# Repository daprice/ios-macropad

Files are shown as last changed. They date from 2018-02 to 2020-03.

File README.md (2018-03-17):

# Airpad
A tiny (3x4 key) bluetooth keypad using low profile mechanical keyboard switches and the Adafruit Feather 32u4 Bluefruit, intended to give you quick access to functions on your iOS device that are normally cumbersome to use. Or a companion to a 60% or smaller keyboard. Your choice.

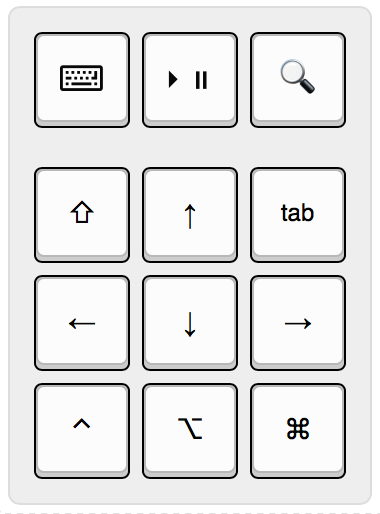
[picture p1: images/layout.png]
view on Keyboard Layout Editor (http://www.keyboard-layout-editor.com/#/gists/3676b2810c4b6d54954320ad40bb4f09)


## PCB
Find the [KiCad](http://kicad-pcb.org) source files in the PCB folder.

### Switches
This PCB uses mechanical keyswitches compatible with Kailh PG1350, commonly known as "Choc" Low Profile. These are available in various varieties and in small quantities from vendors like [NovelKeys](https://novelkeys.xyz) in the US.

### Gerber and drill files
The files in `PCB/gerbers` were produced by KiCad 4.0.7 using [OSH Park's recommended settings](https://docs.oshpark.com/design-tools/kicad/generating-kicad-gerbers/). If you have the PCB manufactured somewhere else, you may change the names of the files at the very least (your board house should provide their desired filenames and any special settings they require).

## Acrylic case
The case is currently a work in progress; further documentation will be provided when it's complete.

## Firmware
Firmware will be based on [QMK](http://qmk.fm).

------------------------



This work is licensed under a [Creative Commons Attribution-ShareAlike 4.0 International License](http://creativecommons.org/licenses/by-sa/4.0/).

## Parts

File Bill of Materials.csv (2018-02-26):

Quantity | Component | Mfg Part # | Description | URL | Unit price as of 2/23/18 | Total price
1 | N/A | 1570 | LiPo 3.7v 100mAh | https://www.adafruit.com/product/1570 or https://www.digikey.com/product-detail/en/adafruit-industries-llc/1570/1528-1837-ND/5054546 | $5.95 | $5.95
1 | U1 | 2829 | Feather 32u4 Bluefruit LE (loose headers) | https://www.adafruit.com/product/2829 or https://www.digikey.com/product-detail/en/adafruit-industries-llc/2829/1528-1517-ND/5774320 | $29.95 | $29.95
1 | QI1 | 1901 | QI wireless power receiver | https://www.adafruit.com/product/1901 | $14.95 | $14.95
12 | SW(Row):(Col) | PG1350 | Kailh choc keyswitch, any color | https://novelkeys.xyz/collections/switches/products/kailh-low-profile-switches | $0.35 | $4.20
12 | D(Row):(Col) | 1N4148 | SOD-123 package | https://www.digikey.com/scripts/DkSearch/dksus.dll?Detail&itemSeq=252997464&uq=636550406655446122 | $0.11 | $1.36
1 | D1 | MBR120 | Schottky diode, SOD-123F | https://www.digikey.com/scripts/DkSearch/dksus.dll?Detail&itemSeq=252997545&uq=636550409386409981 | $0.42 | $0.42
1 | SW1 | GPTS203211B | SPST On/off pushbutton | https://www.digikey.com/product-detail/en/cw-industries/GPTS203211B/CW181-ND/3190590 | $0.74 | $0.74
 | Total |  |  |  |  | $57.57

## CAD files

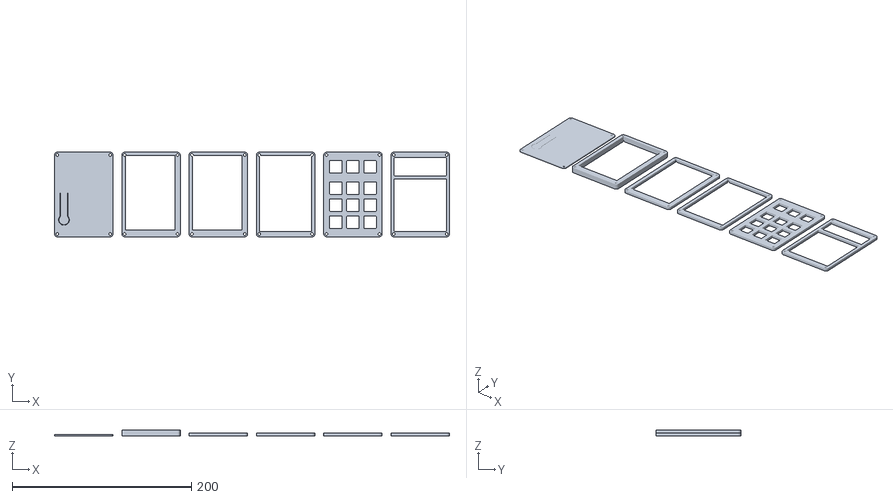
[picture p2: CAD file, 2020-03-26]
Acrylic case/stl/case layers.stl
440.1 x 94.3 x 6.35

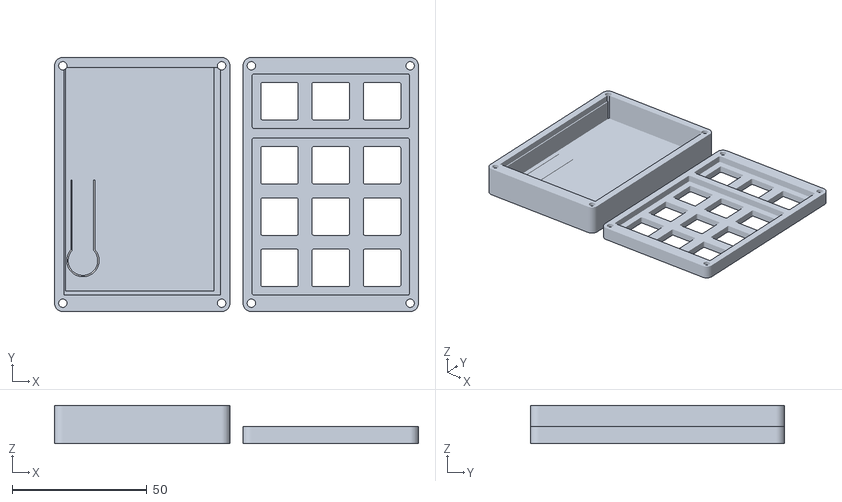
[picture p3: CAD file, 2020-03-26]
Acrylic case/stl/3d_printable.stl
135.2 x 94.3 x 14.3

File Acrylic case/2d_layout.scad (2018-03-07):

// 2-dimensional layout of case layers
// Render this and export to SVG or DXF from OpenSCAD to get laser cutting files (these may still need minor cleanup afterwards)

use <assembly.scad>;
include <layers.scad>;

spacing = 10;

layer_count = len(layer_thicknesses);

// 2d layout
layout_layers(layer = 0, extraSpace = spacing);

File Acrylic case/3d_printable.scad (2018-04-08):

// 3D printable version of the case
// Note that this essentially comes out as a partially-preassembled version of the laser cut design and isn't optimized for 3D printing in any way.

use <assembly.scad>;
include <layers.scad>;

// bottom part
stack_layers(layer = 0, maxLayer = 3);

// top part
translate([max_layer_size[0] + 10, 0, 0]) {
	stack_layers(4);
}

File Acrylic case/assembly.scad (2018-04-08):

/*
	Exploded and solid views of assembled case
	this file displays visualizations that are intended to help while you edit layers.scad, but can also be rendered and exported to STL for rapid prototyping with a 3d printer
*/

include <layers.scad>;

display_spacing = 15;

layer_count = len(layer_thicknesses);

// exploded stack
%translate([0, 0, 0]) {
	stack_layers(layer=0, extraSpace = display_spacing);
}

// solid stack
%translate([-max_layer_size[0], -max_layer_size[1], 0]) {
	stack_layers(layer=0, alpha = 0.8);
}

// layout of 3d layers
translate([display_spacing, -max_layer_size[1] - display_spacing, 0]) {
	layout_layers(extraSpace = display_spacing, 3d = true);
}

module layout_layers(layer = 0, extraSpace = display_spacing, 3d = false) {
	if(!3d) layer_2d(layer);
	else layer_3d(layer);
	
	if(layer + 1 < layer_count) {
		translate([max_layer_size[0] + extraSpace, 0, 0]) {
			layout_layers(layer = layer + 1, extraSpace = extraSpace, 3d = 3d);
		}
	}
}

module stack_layers(layer = 0, maxLayer = -1, extraSpace = 0, alpha = 1) {
	value = (layer)/len(layer_thicknesses)/3 + 0.4;
	
	layer_3d(layer, color = [value, value, value, alpha]);
	
	if(layer + 1 < layer_count && (maxLayer == -1 || layer < maxLayer)) {
		translate([0, 0, layer_thicknesses[layer] + extraSpace]) {
			stack_layers(layer = layer + 1, maxLayer = maxLayer, extraSpace = extraSpace, alpha = alpha);
		}
	}
}

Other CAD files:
Acrylic case/layers.scad
Acrylic case/layout.scad

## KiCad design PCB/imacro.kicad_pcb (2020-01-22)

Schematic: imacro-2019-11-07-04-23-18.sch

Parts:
D0:0, D0:1, D0:2, D1:0, D1:1, D1:2, D2:0, D2:1, D2:2, D3:0, D3:1, D3:2: 1N4148; D_SOD-123
D1: MBR120; D_SOD-123F
QI1: QI_Receiver; QI_connector
SW0:0, SW0:1, SW0:2, SW1:0, SW1:1, SW1:2, SW2:0, SW2:1, SW2:2, SW3:0, SW3:1, SW3:2: Choc; PG1350
SW1: TOGGLE; GPTS_SPST_Pushbutton
U1: Feather32u4Bluefruit

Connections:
/5V_USB: D1.1, U1.3
/COL0: D0:0.1, D1:0.1, D2:0.1, D3:0.1, U1.9
/COL1: D0:1.1, D1:1.1, D2:1.1, D3:1.1, U1.15
/COL2: D0:2.1, D1:2.1, D2:2.1, D3:2.1, U1.14
/ROW0: SW0:0.1, SW0:1.1, SW0:2.1, U1.5
/ROW1: SW1:0.1, SW1:1.1, SW1:2.1, U1.6
/ROW2: SW2:0.1, SW2:1.1, SW2:2.1, U1.7
/ROW3: SW3:0.1, SW3:1.1, SW3:2.1, U1.19
GND: QI1.2, SW1.1 (A), U1.25
unnamed: D0:0.2, SW0:0.2
unnamed: D0:1.2, SW0:1.2
unnamed: D0:2.2, SW0:2.2
unnamed: D1.2, QI1.1
unnamed: D1:0.2, SW1:0.2
unnamed: D1:1.2, SW1:1.2
unnamed: D1:2.2, SW1:2.2
unnamed: D2:0.2, SW2:0.2
unnamed: D2:1.2, SW2:1.2
unnamed: D2:2.2, SW2:2.2
unnamed: D3:0.2, SW3:0.2
unnamed: D3:1.2, SW3:1.2
unnamed: D3:2.2, SW3:2.2
unnamed: SW1.2 (B), U1.2

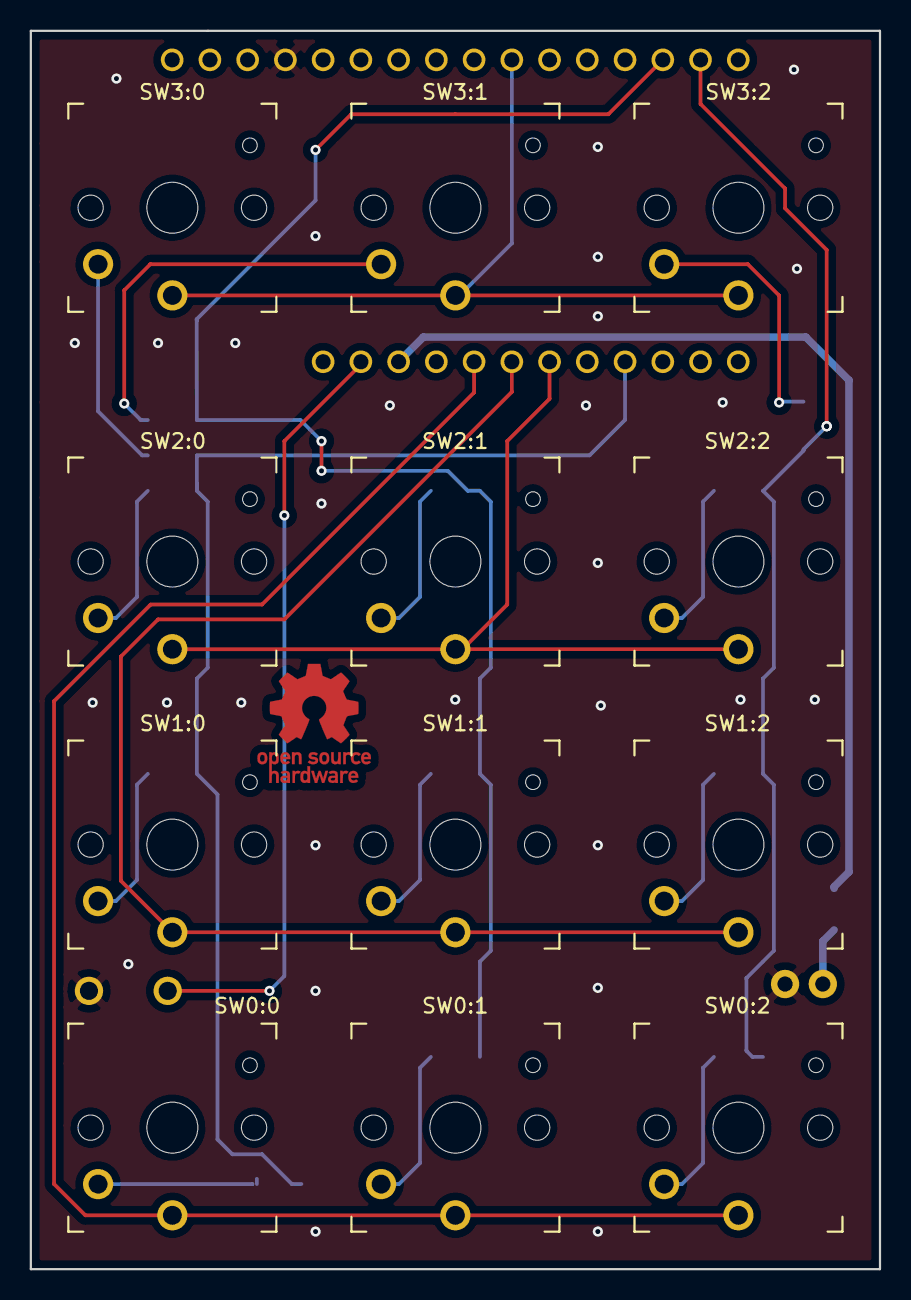
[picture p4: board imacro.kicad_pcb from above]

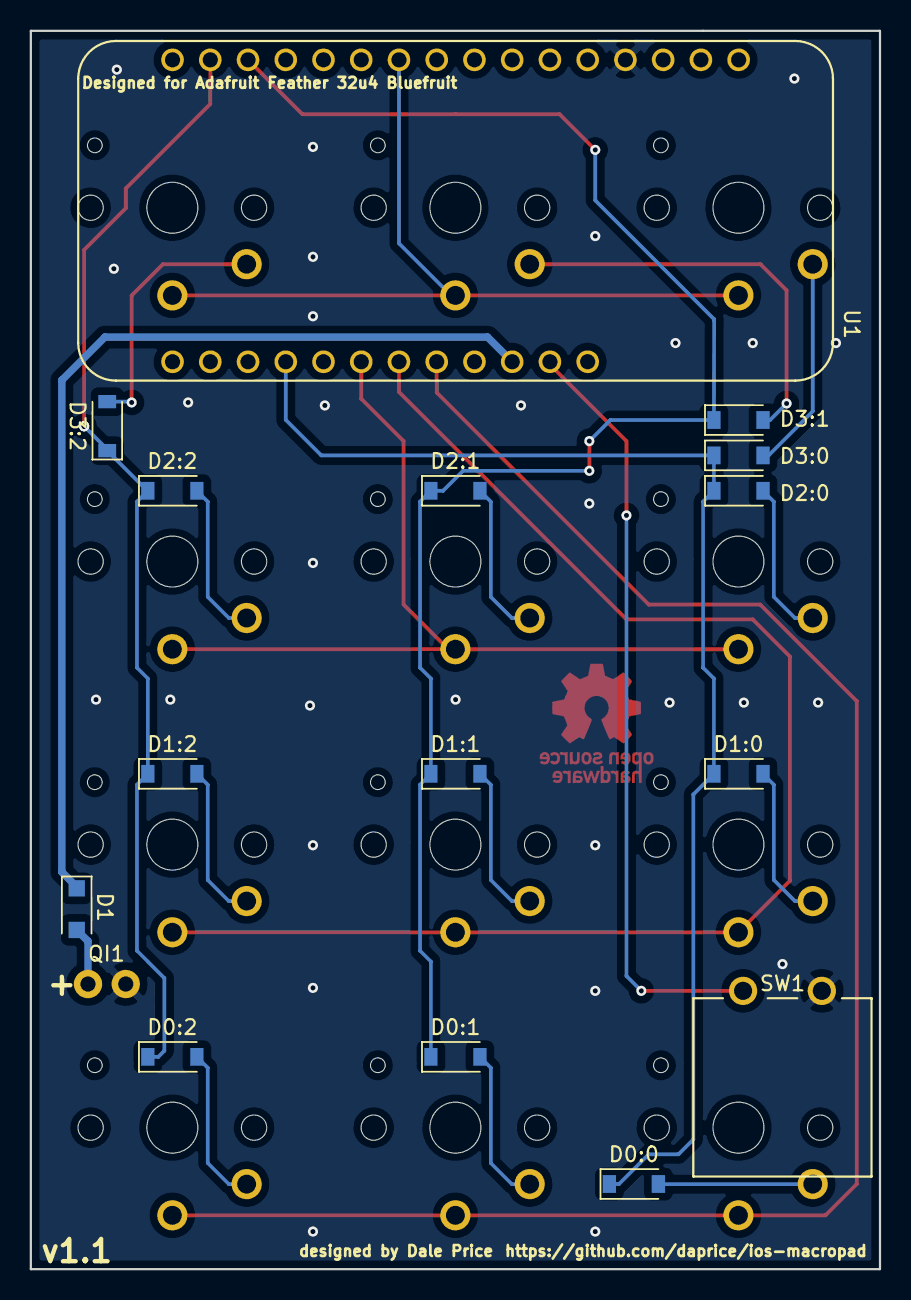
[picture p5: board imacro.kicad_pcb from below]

Board: 2 copper layers, 57.2 x 83.3 mm, 28 parts (16 on the bottom side), 23 nets.

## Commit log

2018-02-22 initial commit of schematic and footprint for the feather32u4
    [imacro.kicad_pcb, imacro.sch]
2018-02-22 add footprint for kailh pg1350 switch
    [imacro.sch]
2018-02-23 create board layout
    [imacro.sch]
2018-02-23 Finish PCB layout; add necessary footprints to library; adjust pad drill size for key switches
    [imacro.kicad_pcb, imacro.sch]
2018-02-23 adjust some text on the silkscreen
    [imacro.kicad_pcb]
2018-02-23 adjust mask clearance to OSH Park spec
    [imacro.kicad_pcb]
2018-02-24 Don’t use pin 9 on the feather so it can be used to read the battery level
    [imacro.kicad_pcb, imacro.sch]
2018-02-25 accomodate smaller case; rotate Feather board around for new battery cable position; improve trace routing somewhat
    [imacro.kicad_pcb, imacro.sch]
2018-02-26 Move D0:0 for power button clearance
    [imacro.kicad_pcb]
2018-02-26 Add BoM
    [Bill of Materials.csv]
2018-02-28 organize project folders; generate gerber files; add readme
    [imacro-B.Cu.gbl, imacro-B.Mask.gbs, imacro-B.SilkS.gbo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]
2018-03-07 Create OpenSCAD templates for case design
    [2d_layout.scad, assembly.scad, layers.scad]
2018-03-07 Create basic layer shape and bolt holes
    [layers.scad]
2018-03-07 position and size screw holes correctly
    [layers.scad]
2018-03-12 Change name to “Airpad”
2018-03-17 Design upper 2 layers of acrylic case using keyboard_parts library; add 3d-rendered layout of layers to assembly.scad for 3d printing prototypes; define key layout
    [assembly.scad, layers.scad, layout.scad]
2018-03-21 Improve switch footprints (requires daprice/keyswitches.pretty ); increase annular ring size on other footprints; add positive indicator to Qi charger connection
    [imacro-B.Cu.gbl, imacro-B.Mask.gbs, imacro-B.SilkS.gbo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]
2018-04-08 initial design for layers 0-3
    [case layers.stl, layers.scad]
2018-04-08 make rudimentary 3d printable case model
    [3d_printable.scad, 3d_printable.stl, assembly.scad]
2018-04-08 Widen side bezels for rigidity;
    When using laser cut layers, the thinner side bezels would squeeze in easily when holding the keypad. Now they shouldn’t.
    [3d_printable.stl, case layers.stl, layers.scad]
2019-11-07 Open PCB in Kicad v5 and let it do its thing to update stuff (I think it did?)
    [imacro-2019-11-07-04-23-18.sch, imacro.kicad_pcb]
2019-11-10 Update keyboard_parts lib; define and pass key unit size as required by this library version
    [layers.scad, layout.scad]
2020-01-13 Update to newer keyswitch footprint library version; update SPST pushbutton footprint to include component outline in silkscreen
    [imacro.kicad_pcb]
2020-01-17 Clean up some traces; avoid vias in power trace; avoid vias under components
    [imacro.kicad_pcb]
2020-01-22 Add stitching vias in ground fill
    [imacro.kicad_pcb]
2020-01-22 Generate updated gerber and drill files
    [imacro-B.Cu.gbl, imacro-B.Mask.gbs, imacro-B.SilkS.gbo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]
2020-03-26 Slightly increase clearance around keycaps to accommodate the slightly off center caps I got from MKUltra
    [layers.scad]
2020-03-26 Add flexible button presser cover
    [layers.scad]
2020-03-26 Render STLs
    [3d_printable.stl, case layers.stl]

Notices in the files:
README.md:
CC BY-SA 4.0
